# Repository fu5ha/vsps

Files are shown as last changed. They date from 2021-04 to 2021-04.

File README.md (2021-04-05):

# VSPS

This is a design for a power supply board and casing for the [VSPS (Very Simple Phono Stage)](http://phonoclone.com/diy-pho5.html) from RJM Audio.

Includes PCB design for power supply board, ready-to-print and CAD files for casing and adapter plates for both power supply unit
and main unit.

## Main Unit

image front
back
inside

### Main unit BOM

You'll want a VSPS kit (or source your own) from RJM Audio: <http://phonoclone.com/pcb.html>

Connectors/receptacles BOM for the enclosure unit as designed: <https://www.mouser.com/ProjectManager/ProjectDetail.aspx?AccessID=c72ca91d05>

Then you'll want an enclosure. The CAD files have been designed for [this case](http://phonoclone.com/pcb.html) (the same one as for the power unit).

### CAD

Download zipped CAD files from [the Releases page](https://github.com/termhn/vsps-power/releases)

## Power Supply Unit

image inside
image outside

### Power supply BOM

Electronic parts BOM: <https://www.mouser.com/ProjectManager/ProjectDetail.aspx?AccessID=cfbaef526f>

Also, you'll need an enclosure. It is designed to work in this enclosure: <https://www.amazon.com/gp/product/B07HBT2CGK>

You'll need to sand down the sides of the PCB slightly at which point it will be a nice pressure fit into the PCB groove built into that enclosure.

### CAD

Download zipped CAD files from [the Releases page](https://github.com/termhn/vsps-power/releases)

### Gerbers

Download zipped gerbers from [the Releases page](https://github.com/termhn/vsps-power/releases)

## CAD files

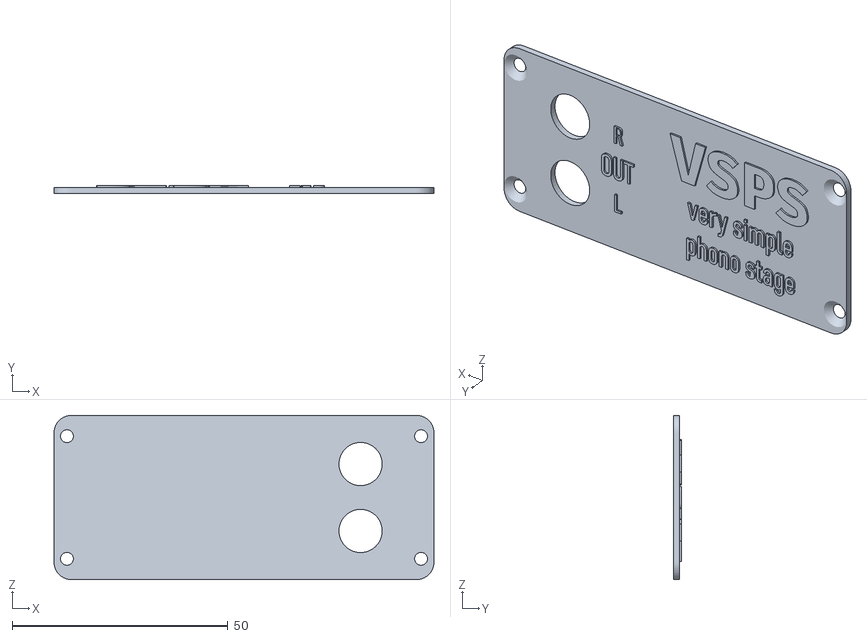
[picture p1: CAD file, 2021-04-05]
cad/main_front_plate.stl
88.0 x 1.80 x 38.0

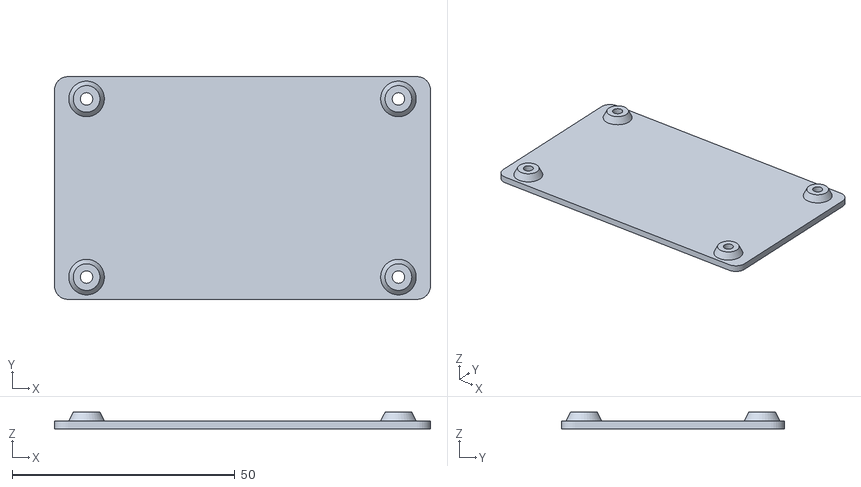
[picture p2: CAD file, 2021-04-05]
cad/main_pcb_plate.stl
84.4 x 50.0 x 3.80

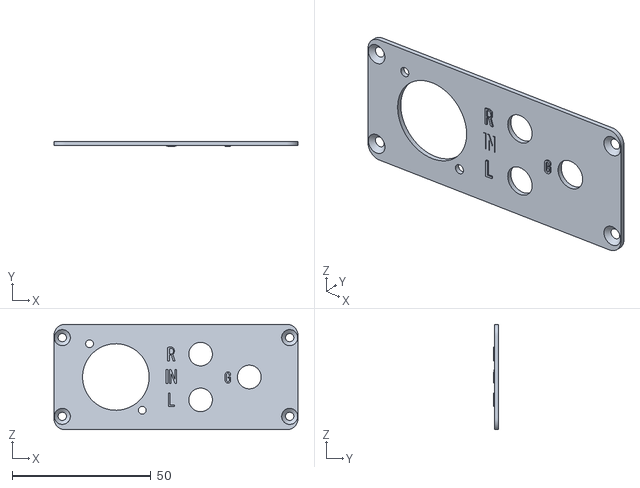
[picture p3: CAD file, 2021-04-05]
cad/main_back_plate.stl
88.0 x 1.80 x 38.0

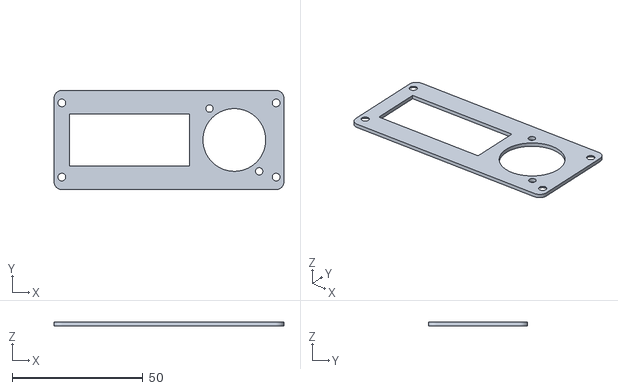
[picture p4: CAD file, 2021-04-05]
cad/power_front_plate.stl
88.0 x 38.0 x 1.40

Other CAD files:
cad/VSPS main casing.f3d
cad/vsps power front plate.f3d

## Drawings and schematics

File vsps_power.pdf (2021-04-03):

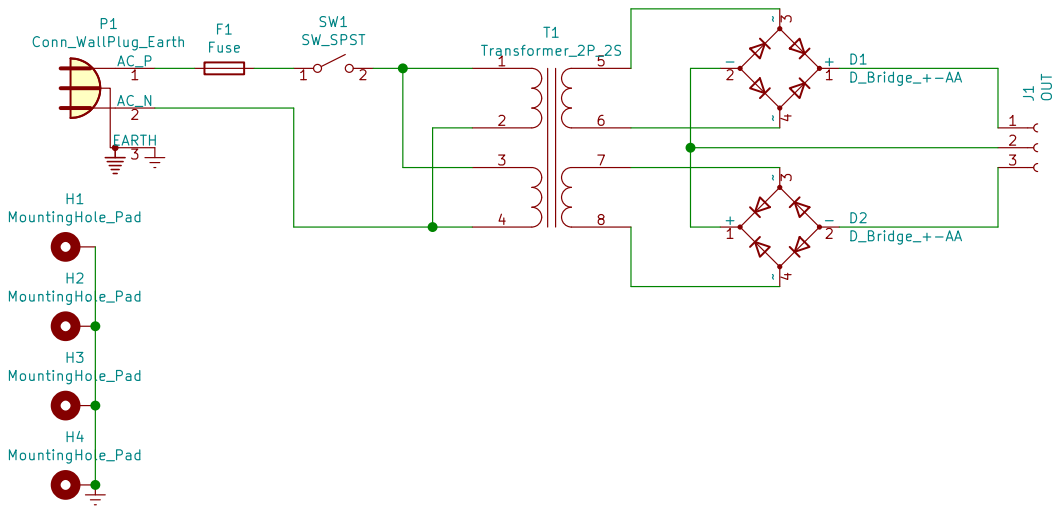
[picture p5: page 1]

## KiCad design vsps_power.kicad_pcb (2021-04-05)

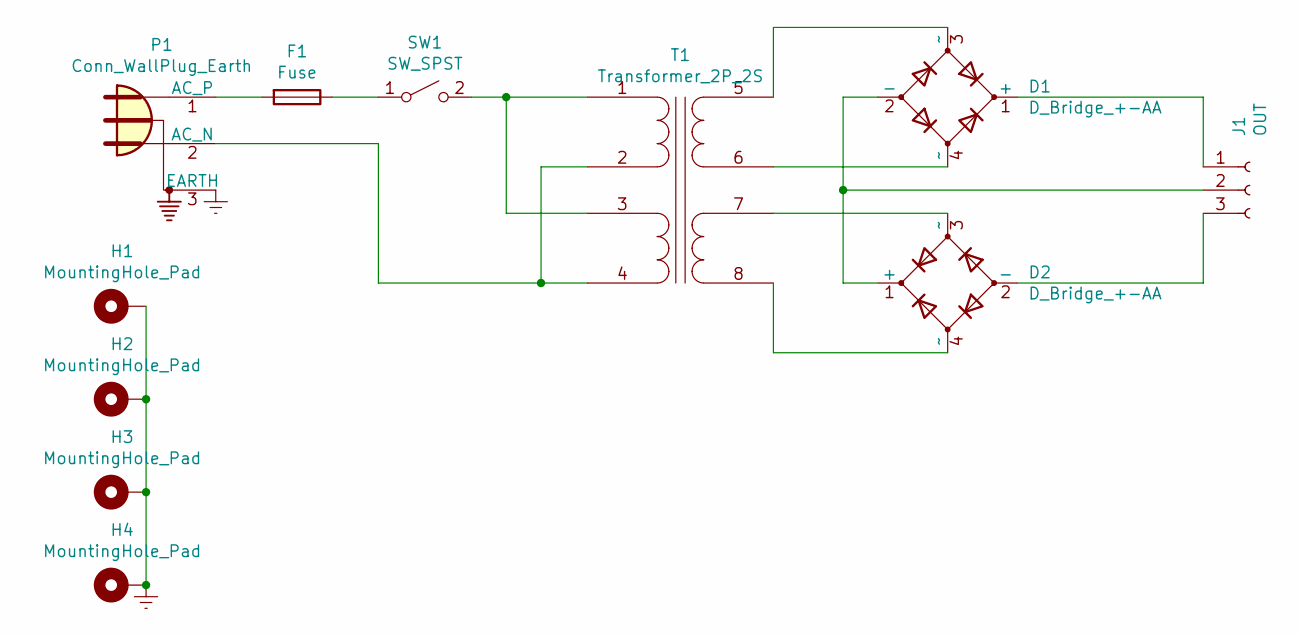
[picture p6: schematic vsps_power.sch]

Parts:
D1, D2: D_Bridge_+-AA; Diode_Bridge_15.1x15.1x6.3mm_P10.9mm
F1: Fuse; Fuseholder_5x20mm_DualClip
H1, H2, H3, H4: MountingHole_Pad; MountingHole_3.2mm_M3_Pad
J1: OUT; SolderWire-0.5sqmm_1x03_P4.6mm_D0.9mm_OD2.1mm
P1: Conn_WallPlug_Earth; SolderWire-1.5sqmm_1x03_P6mm_D1.7mm_OD3mm
SW1: SW_SPST; SolderWire-1.5sqmm_1x02_P6mm_D1.7mm_OD3mm
T1: Transformer_2P_2S; Transformer_Triad_FP24-250

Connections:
Earth: H1.1, H2.1, H3.1, H4.1, P1.3 (EARTH)
unnamed: D1.1 (+), J1.1
unnamed: D1.2 (-), D2.1 (+), J1.2
unnamed: D1.3 (~~), T1.5 (SA)
unnamed: D1.4 (~~), T1.6 (SB)
unnamed: D2.2 (-), J1.3
unnamed: D2.3 (~~), T1.7 (SC)
unnamed: D2.4 (~~), T1.8 (SD)
unnamed: F1.1, SW1.1 (A)
unnamed: F1.2, P1.1 (AC_P)
unnamed: P1.2 (AC_N), T1.2 (SB), T1.4 (SD)
unnamed: SW1.2 (B), T1.1 (SA), T1.3 (SC)

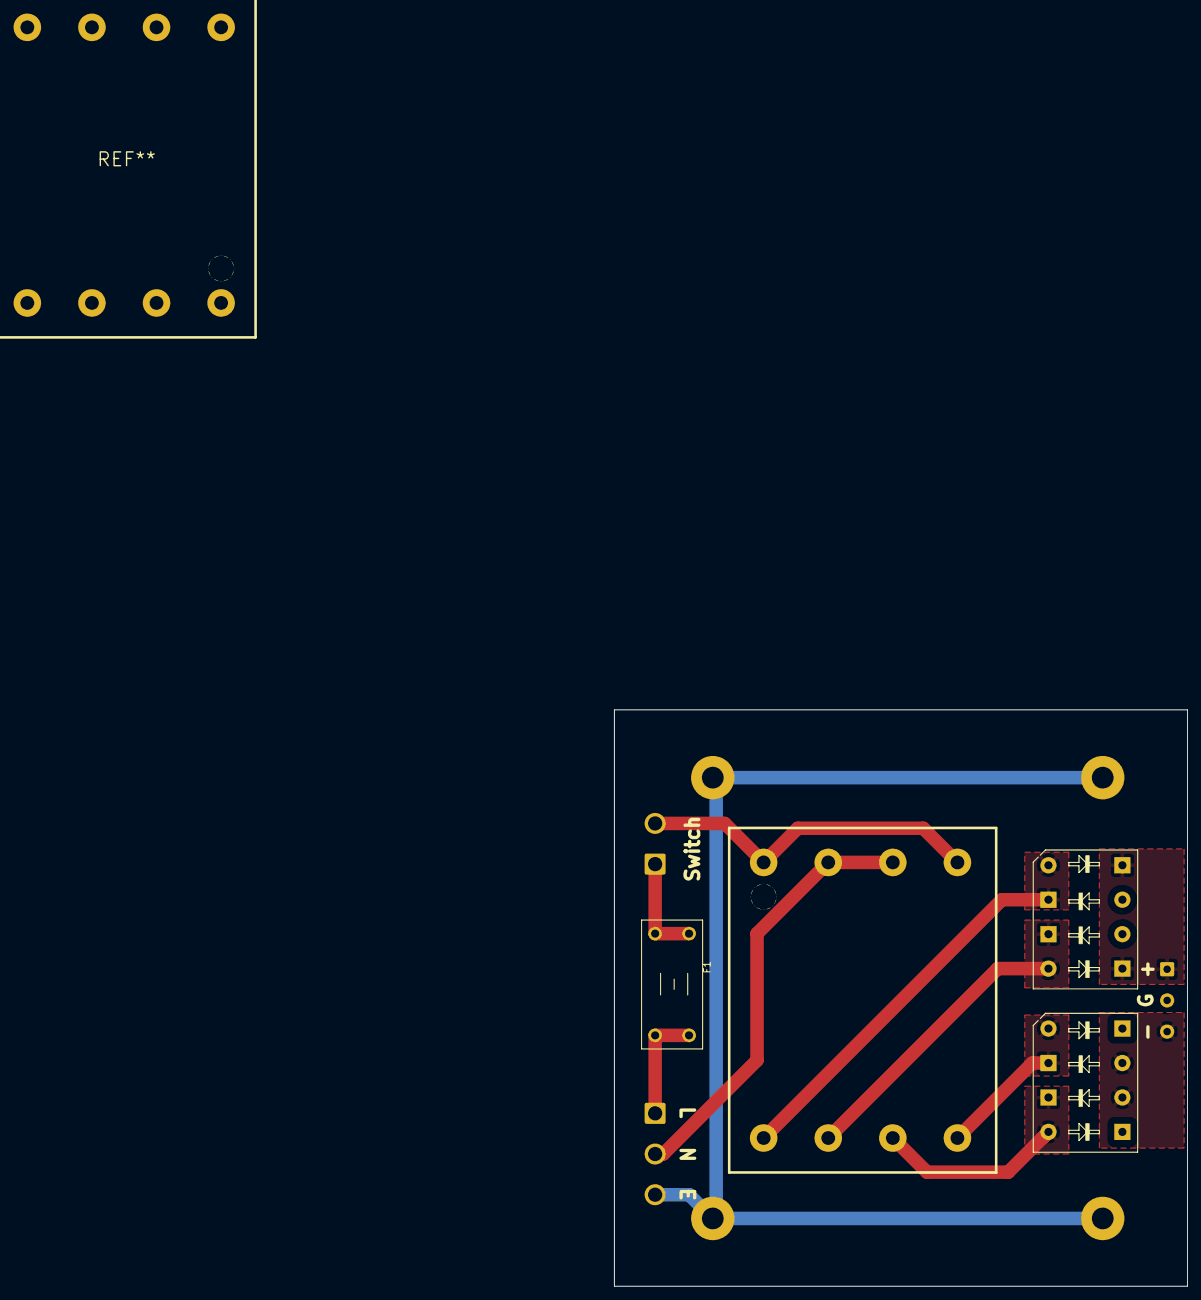
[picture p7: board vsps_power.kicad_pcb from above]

Board: 2 copper layers, 84.5 x 85.0 mm, 11 parts (1 on the bottom side), 12 nets.

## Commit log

2021-04-03 add front plate stl
    [front_plate_3dprint.stl]
2021-04-05 add cad and section about main unit
    [VSPS main casing.f3d, front_plate_3dprint.stl, main_back_plate.stl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]
2021-04-05 correct transformer footprint
    [vsps_power-B_Cu.gbl, vsps_power-B_Mask.gbs, vsps_power-B_SilkS.gbo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]
